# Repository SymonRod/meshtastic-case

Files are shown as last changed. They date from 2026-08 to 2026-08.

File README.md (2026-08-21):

# meshtastic-case

Custodia stampabile in 3D per un nodo Meshtastic, con guarnizione O-ring.

Generata in modo interamente parametrico via script Python/`bpy` per Blender:
nessun file `.blend` da versionare, tutte le quote sono costanti in cima a
[`scripts/build_case.py`](scripts/build_case.py), unica fonte di verità del
progetto.

| Base | Coperchio |
|---|---|
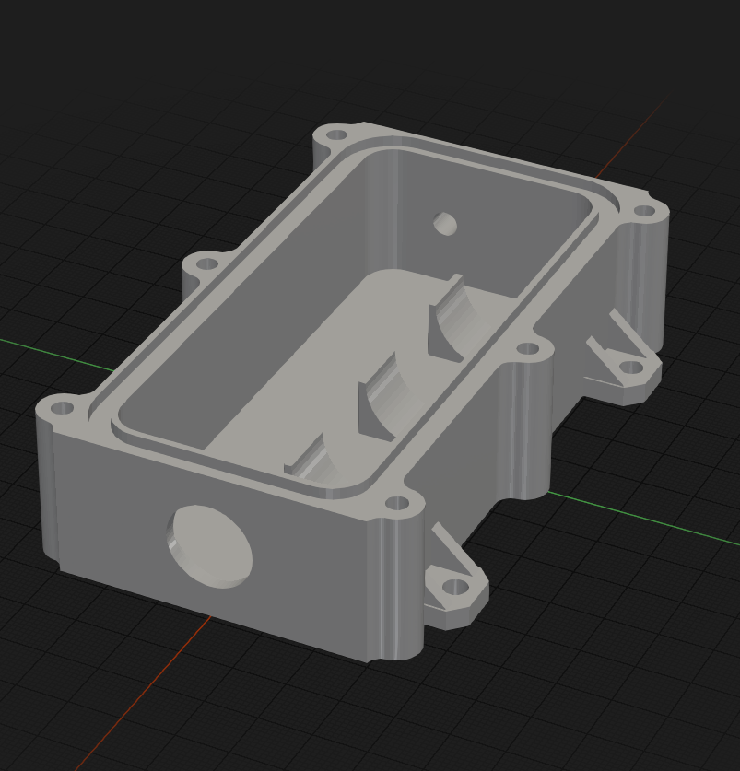
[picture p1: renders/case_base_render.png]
Base della custodia, vista interna
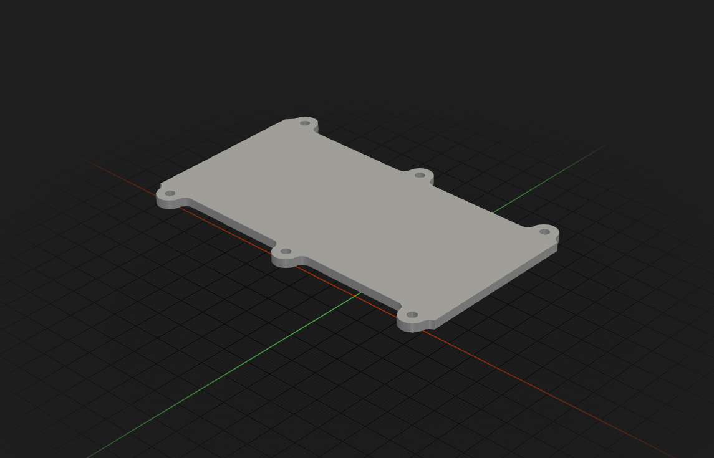
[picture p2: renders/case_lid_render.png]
Coperchio
|  |  |

## Contenuto

- Cella **21700** (21 × 70 mm) in sella semicilindrica sul lato −Y, su tre
  bande da 12 mm anziché un blocco pieno
- **Seeed XIAO nRF52840 + Wio-SX1262** (stack 21 × 17.8 × 13 mm), appoggiato
  sul pavimento nella striscia libera lato +Y, fissato a biadesivo (nessun
  supporto stampato, nessuna asola USB)
- Connettore **N bulkhead** (filetto 5/8"-24) sulla parete −X, con scasso
  interno per dado e chiave
- **Guarnizione O-ring**: corda di silicone Ø3 mm in cava continua sul bordo
  della base (~312 mm di sviluppo)
- Chiusura con **6 viti M3** su inserti a caldo, in lug esterni fuori dalla
  linea di tenuta
- **4 alette M4** complanari al pavimento per il fissaggio al dorso del
  pannello solare (o a palo)
- Passacavo Ø5 nella parete +X (opposta all'antenna), da sigillare a silicone

Ingombro esterno: **117.8 × 58.8 × 32.1 mm**, **80.8 mm** in Y contando le
alette.

Il dettaglio di ogni scelta progettuale (perché le pareti sono a 6.4 mm,
perché la sella è divisa in tre bande, i vincoli sullo scasso del
connettore, ecc.) è documentato in [`CLAUDE.md`](CLAUDE.md).

### Aggiornamento della vecchia cava O-ring

Per una base già stampata con la cava 3,8 × 2,2 mm, stampare una copia di
[`oring_groove_shim.stl`](models/oring_groove_shim.stl) e adagiarla centrata sul
fondo della cava prima della corda Ø3. Il rialzo è alto 0,20 mm e largo 1,80:
porta lo schiacciamento dal 27% al 33%, lasciando ai lati il volume necessario
alla deformazione del silicone. Non serve ristampare la base.

Stampare piatto, senza supporti, con primo layer da **0,20 mm**, scala 100% e
senza compensazioni Z. Se serve tenerlo fermo durante il montaggio, usare solo
pochi punti sottili di adesivo; grumi o sovrapposizioni alterano la tenuta.

Se serve più pressione, usare invece
[`oring_groove_shim_high_compression.stl`](models/oring_groove_shim_high_compression.stl):
è alto 0,30 mm e largo 1,20 mm, porta la compressione a circa il 37% e conserva
lo stesso volume libero. Stampare con primo layer da **0,30 mm** e non
sovrapporlo allo spessore standard.

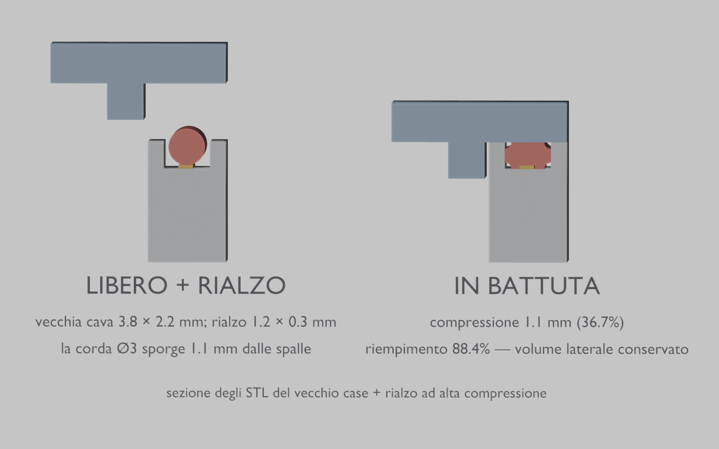
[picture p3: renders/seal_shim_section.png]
Sezione del vecchio case con rialzo ad alta compressione


## Montatura del pannello solare

Accessorio opzionale ([`build_mount.py`](scripts/build_mount.py)) per appendere un
pannello da 170 × 170 mm **senza forarlo e senza toccare la custodia**: **un
pezzo solo** che si infila fra le teste delle sei viti M3 e il coperchio, e
prende il pannello per i quattro angoli con otto linguette a scatto.

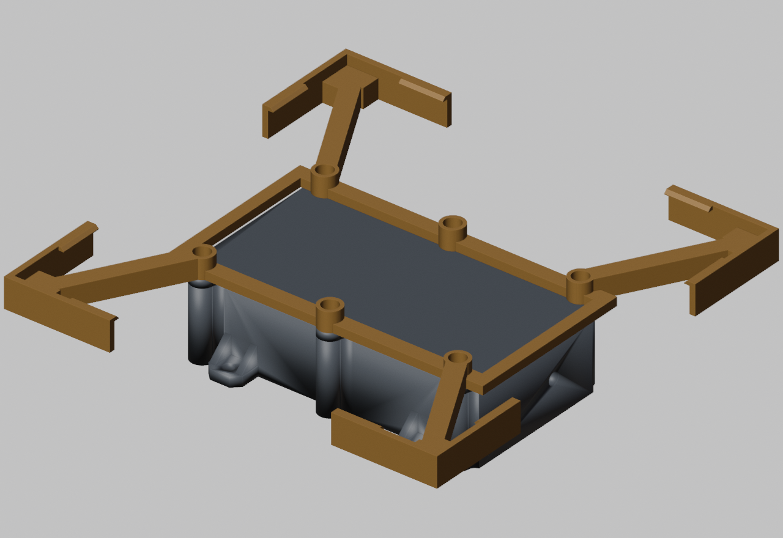
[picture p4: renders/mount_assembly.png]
La montatura montata sulla custodia


- **Un solo pezzo, nessuna vite in più**: le sei M3 del coperchio diventano
  M3×12 e basta (le teste stanno annegate nello svaso, 2.3 mm sotto il
  pannello)
- **Lastra da 3.5 mm**, che sale a 8 solo dove serve: i sei bossi delle viti,
  i quattro bracci e le teste d'angolo
- **Anello chiuso su tutte e sei le viti**: tre viti in fila, da sole, non
  bloccherebbero la rotazione attorno alla loro linea
- Del coperchio tocca **solo i lug e la striscia sopra le pareti**, mai la
  campata centrale: il coperchio non viene inarcato e la tenuta non si apre
- **Otto linguette a scatto** (due per angolo), premibili dal fianco per sganciare
- Testa d'angolo a **L**: due lamelle (fermo laterale e linguetta nello stesso
  prisma) e due rami di piano d'appoggio che ne fissano la radice — niente
  blocco pieno d'angolo, niente aria di manovra da rispettare
- Tutto estruso in verticale dal piano di stampa: **nessun supporto**, nessun
  piedino, appoggio pieno sul piatto
- Il pannello è di misura **fissa**: si cambia `PANEL_W`/`PANEL_H` e si
  ristampa
- ~23 g in PETG, ingombro 176.2 × 176.2 × 12.2 mm

| Dettaglio di una testa d'angolo |
|---|
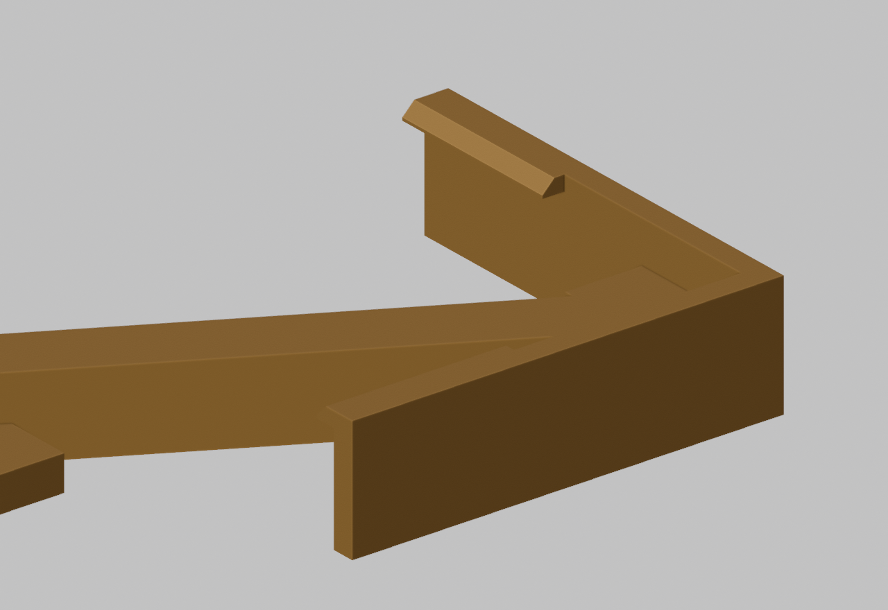
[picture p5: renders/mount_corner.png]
Testa d'angolo a L con le due lamelle
|  |

Come si aggancia, in sezione attraverso una linguetta: il pannello scende, la
rampa a 45° apre la linguetta verso l'esterno di 1.5 mm, e appena il dorso
appoggia sul piano il dente scatta sopra la faccia anteriore.

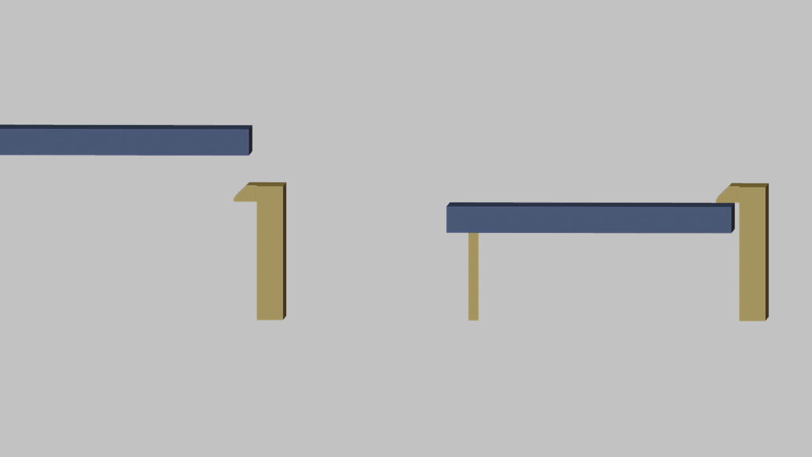
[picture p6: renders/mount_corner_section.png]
Sezione: pannello che scende e pannello agganciato


## Struttura del progetto

- `scripts/` — generatori parametrici, verifiche geometriche e script di render
- `models/` — tutti gli STL pronti per lo slicer
- `renders/` — immagini e sezioni tecniche generate
- `tools/` — utility di sviluppo non necessarie per stampare il progetto

Gli script risolvono i percorsi a partire dalla root del progetto: possono
essere lanciati da qualunque directory e scrivono sempre in `models/` o
`renders/`.

## Rigenerare gli STL

Richiede [Blender](https://www.blender.org/) (testato con 4.x/5.x):

```sh
blender --background --factory-startup --python scripts/build_case.py
blender --background --factory-startup --python scripts/build_mount.py
blender --background --factory-startup --python scripts/build_oring_shim.py
```

Gli script cancellano la scena, la ricostruiscono da zero ed esportano gli STL
in `models/`.

## Stampa

- Base: apertura verso l'alto, nessun supporto necessario
- Coperchio: piatto, nessun supporto
- Rialzo O-ring: piatto, un solo layer da 0,20 mm, nessun supporto
- Rialzo O-ring ad alta compressione: piatto, un solo layer da 0,30 mm
- Guarnizione: corda di silicone Ø3 mm, giuntata a colla nella cava
- Chiusura: 6 inserti filettati M3 a caldo + viti M3×10 a testa bombata
- Fissaggio: 4 viti/bulloni M4 nelle alette
- Montatura: un pezzo solo, appoggiato sul piatto così com'è; niente supporti,
  ~23 g in PETG. Con la montatura le sei viti diventano **M3×12** (impegno 5.3
  mm nell'inserto) e non serve nient'altro

## Licenza

[MIT](LICENSE)

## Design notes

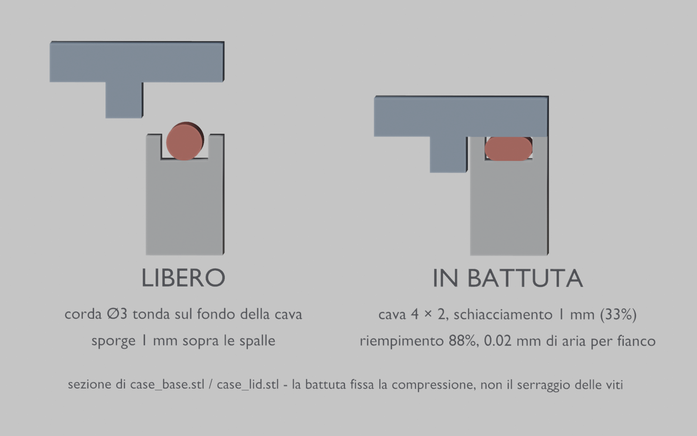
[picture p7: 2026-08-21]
renders/seal_section.png

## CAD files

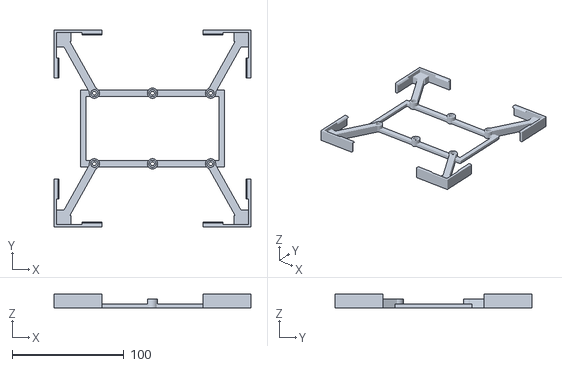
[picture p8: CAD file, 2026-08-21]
models/panel_mount.stl
176.2 x 176.2 x 12.2

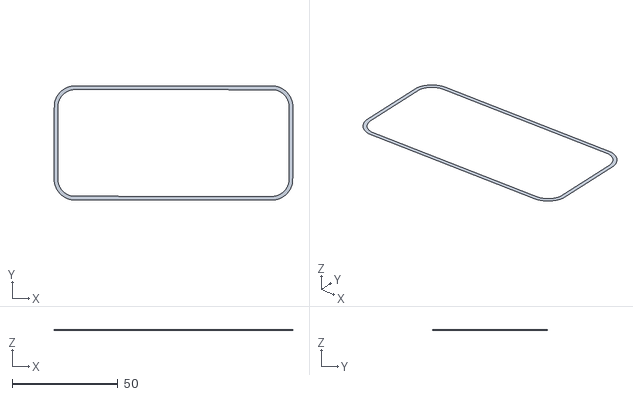
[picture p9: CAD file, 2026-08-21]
models/oring_groove_shim.stl
113.2 x 54.2 x 0.2

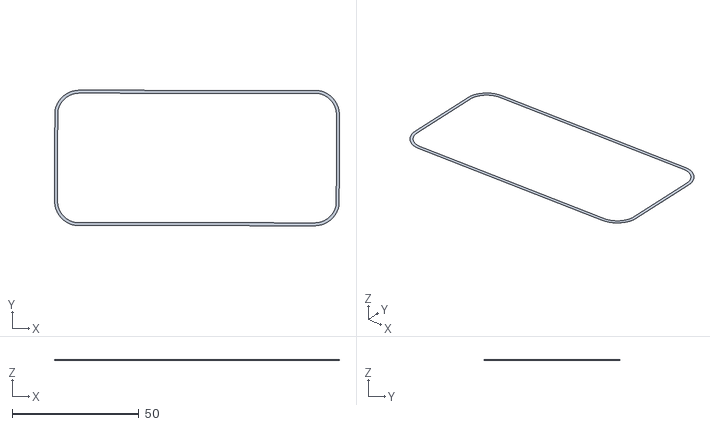
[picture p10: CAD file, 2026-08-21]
models/oring_groove_shim_high_compression.stl
112.6 x 53.6 x 0.3

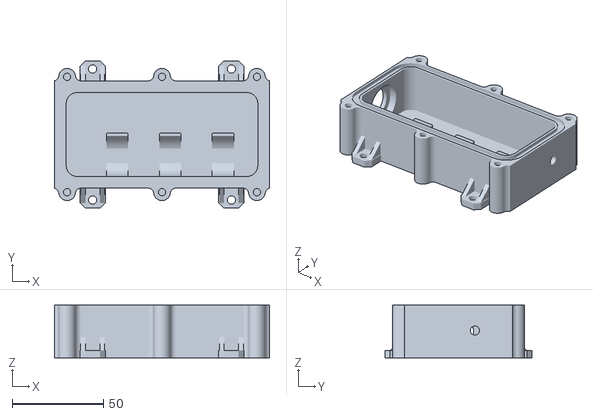
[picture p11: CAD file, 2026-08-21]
models/case_base.stl
117.8 x 80.8 x 28.9

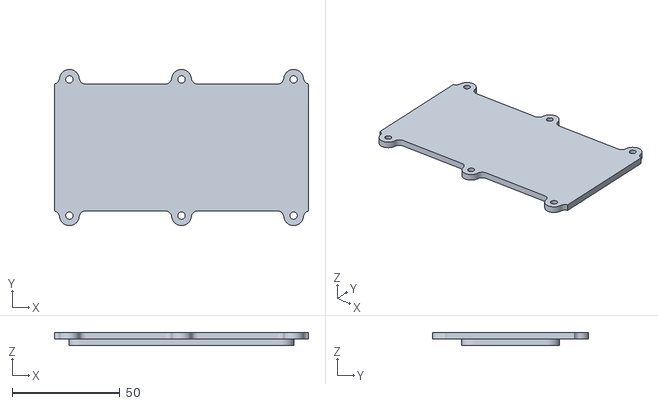
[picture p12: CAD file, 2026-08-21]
models/case_lid.stl
117.8 x 72.4 x 6.20

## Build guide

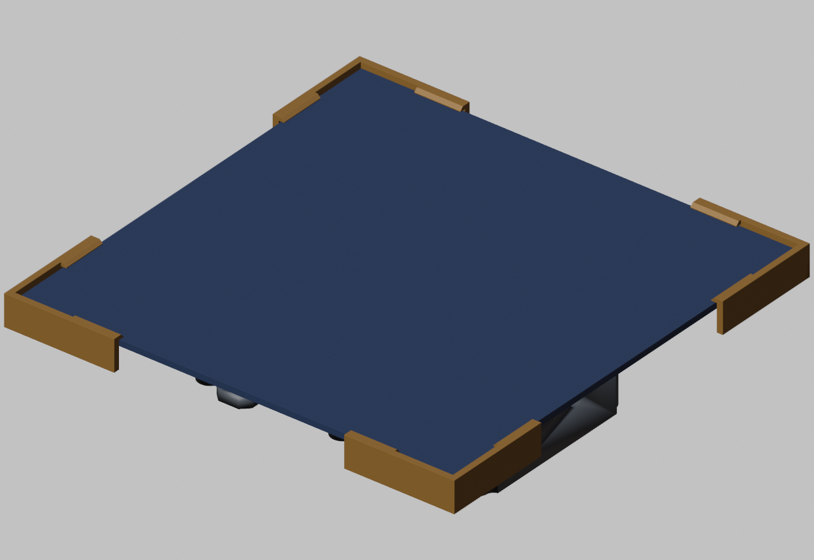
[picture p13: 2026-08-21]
renders/mount_assembly_panel.png

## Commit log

2026-08-19 Initial commit: parametric Meshtastic case with O-ring seal
    Blender/bpy source, generated STLs, and verification script for a
    21700-cell case with N-bulkhead connector mount and M4 fixing ears.
    [case_base.stl, case_lid.stl]
2026-08-19 Montatura per pannello solare: telaio a H sulle 6 viti + 4 clip a scatto
    Accessorio separato, la custodia non viene toccata: nessun foro nuovo,
    nessun inserto nuovo, build_case.py invariato.
    - panel_frame.stl x1: telaio a H che si infila fra le teste delle sei M3
    e il coperchio. Tre viti in fila non bloccherebbero la rotazione attorno
    alla loro linea, quindi non due staffe a U ma un pezzo solo su tutte e
    sei. Appoggia solo sui sei lug, gli unici punti in cui il coperchio e`
    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
    [panel_clip.stl, panel_frame.stl]
2026-08-19 Render in sezione della clip: come il pannello ci si aggancia
    Taglia la clip su una fetta da 8 mm perpendicolare al bordo, in pieno
    dente, e affianca i due stati (pannello che scende / pannello agganciato).
    La fetta serve a togliere dall'inquadratura la linguetta dell'altro bordo,
    che stava dietro e rendeva la sezione illeggibile.
    Claude-Session: https://claude.ai/code/session_01Y6tpg9DKrwZzAfaEtMvMwq
2026-08-19 Montatura del pannello in un pezzo solo, stampabile senza supporti
    Il telaio + 4 clip diventano panel_mount.stl, un pezzo unico. Metà della
    complessità del file (asole, guida a 45°, piastrini, svasi, quattro viti
    autofilettanti) esisteva solo per rendere le clip registrabili: fissata la
    misura del pannello, sparisce tutta.
    Sparisce anche un difetto della versione precedente: il telaio appoggiava su
    sei piedini alti 3.5 con il piano sospeso sopra, e così non si stampava senza
    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
    [panel_clip.stl, panel_frame.stl, panel_mount.stl]
2026-08-19 Lastra sottile con bossi sulle viti, via le alette d'angolo
    L'anello passa da 7 mm pieni a una lastra di 3.5 e sale a 8 solo dove serve:
    i sei bossi delle viti, i quattro bracci e le teste d'angolo. Il volume scende
    da 54.5 a 36.1 cm3 (~25 g contro ~38).
    I bracci invece si alzano da 7 a 8 e si stringono da 9 a 7: sono mensole da
    49 mm caricate dal vento, e in Z la sezione conta al quadrato. A 3 mm, come
    sarebbe venuto assottigliando tutto, andrebbero a ~44 MPa con 13 mm di
    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
    [panel_mount.stl]
2026-08-20 Teste d'angolo piu` semplici e piu` leggere
    Montante e linguetta erano due prismi separati con la stessa sezione nella
    stessa banda: ora sono una lamella sola, dal vertice dell'angolo alla punta.
    Il tratto fasciato dal piano d'appoggio e` il fermo laterale rigido, oltre e`
    la linguetta che flette.
    Via il blocco d'angolo: un quadrato pieno 15 x 15 x 8 per angolo che faceva
    solo da tramite fra montanti, piano e braccio. I due rami del piano si
    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
    [panel_mount.stl]
2026-08-21 Migliora la compressione della guarnizione
    [case_base.stl, case_lid.stl]
2026-08-21 Organizza il progetto e aggiungi gli spessori O-ring
    [case_base.stl, case_lid.stl, oring_groove_shim.stl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]
2026-08-21 Widen solar panel mount fit
    [panel_mount.stl]
